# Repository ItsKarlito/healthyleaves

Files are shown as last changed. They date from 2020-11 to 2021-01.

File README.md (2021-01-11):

# ELEC/COEN 390 Engineering Team Design Project

**HealthyLeaves** is consumer electronics device used to monitor the vitals of any plant. Using a combination of powerful hardware and software, HealthyLeaves guarantees healthier and longer lasting house plants.

## Contributors
Daniel Savin (ELEC)  
Jun Young David Kim (ELEC)  
Karl Noory (ELEC)  
Thomas Tran (COEN)  
Vily Badea (COEN)  

## Supervision
Bipin Patel  
Dr. Wahab Hamou Lhadj  

## Technology Stack
Android Studio IDE  
Arduino C/C++  
Arduino IDE  
ESP32 Microcontroller  
Firebase  
Git  
Java  
KiCAD  
LDR Light Sensor  
SEN0193 Capcitive Moisture Sensor  
TensorFlow  
TMP36 Temperature Sensor  

## App Installation Guide
### Steps
1. Clone project repository.
1. Open PlantMonitor Android project in .software/PlantMonitor.
1. Build Gradle of PlantMonitor Android app.
1. Run PlantMonitor Android app.
1. Open PlantIdentier Android project in .software/PlantIdentifier.
1. Build Gradle of PlantIdentifier Android app.
1. Run PlantIdentifier Android app.
1. You can now access the application called "Healthy Leaves".

### Notes
Make sure the filepath for the SDK manager points to your own directory.  
The build.gradle file will need to specify the version of your own Android Studio version.  
A device is not requiered to run the app.  
To pair the device to our demo device on Karl's plant, enter the device code as "-MLuKU9iZdUl5zLGsuPz".  

## Microcontroller Setup Guide
### Steps
1. Clone project repository.
1. Download and install the [FirebaseESP32](https://www.arduino.cc/reference/en/libraries/firebase-esp32-client/) client library. Import the library into the [Arduino IDE](https://www.arduino.cc/en/software).
1. Open the HealthyLeaves Arduino project located at engineering-team-design-project/hardware/sparkfunESP32/HealthyLeaves/
1. Edit sketch with proper WiFi and Firebase credentials.
1. Attach the HealthyLeaves sensor shield to the SparkFun ESP32 Thing.
1. Connect the SparkFun ESP32 Thing microcontroller to your computer via USB port. Follow the steps [here](https://learn.sparkfun.com/tutorials/esp32-thing-hookup-guide) if the Arduino IDE does not recognise the SparkFun ESP32 Thing.
1. Compile and upload the sketch to the SparkFun ESP32 Thing.
1. Place the end of the moisture sensor located on the HealthyLeaves sensor shield into the plant you want to monitor.

### Notes
A device is not requiered to run the app.  
To pair the device to our demo device on Karl's plant, enter the device code as "-MLuKU9iZdUl5zLGsuPz" in the HealthyLeaves Arduino sketch.  

## Pictures and Screenshots
### Android Application
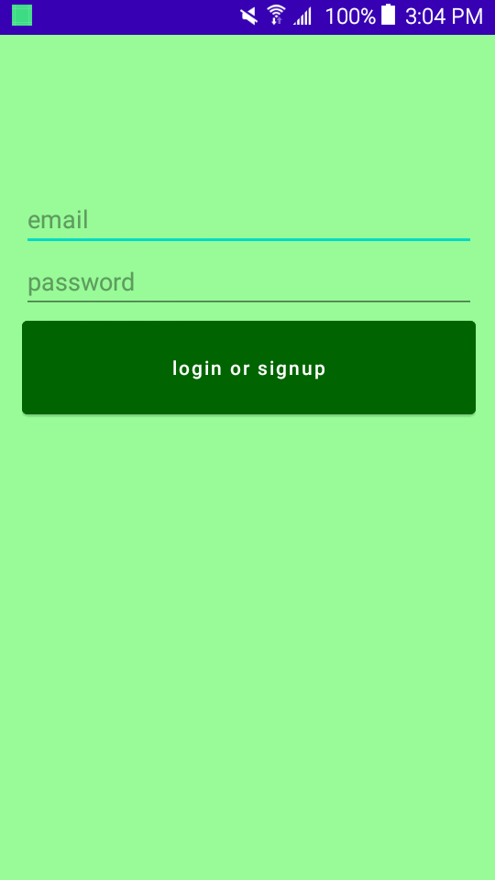
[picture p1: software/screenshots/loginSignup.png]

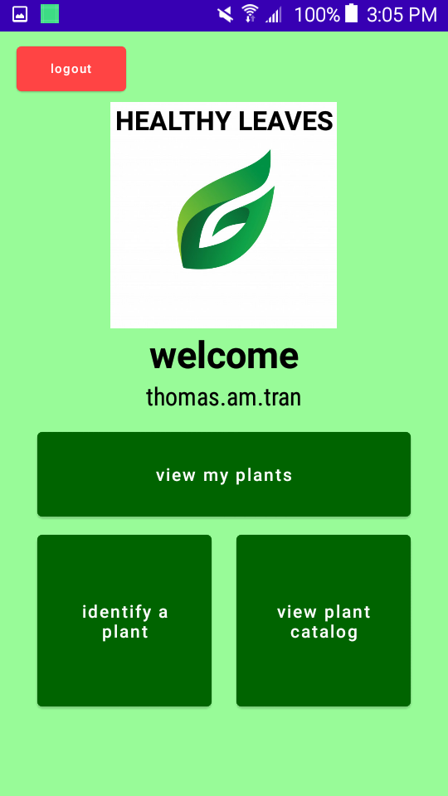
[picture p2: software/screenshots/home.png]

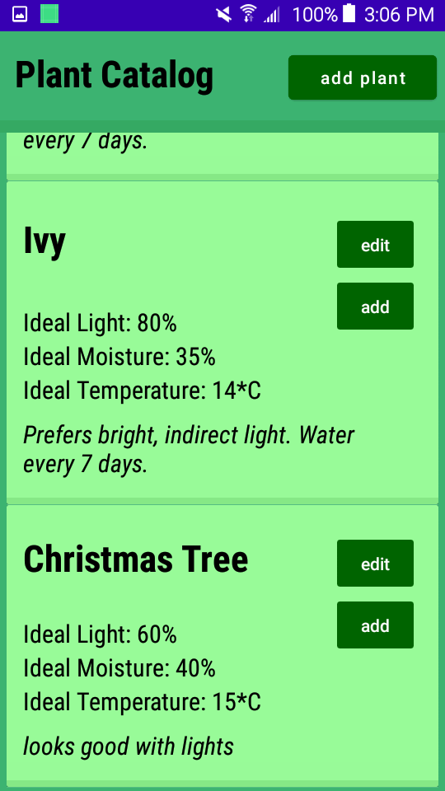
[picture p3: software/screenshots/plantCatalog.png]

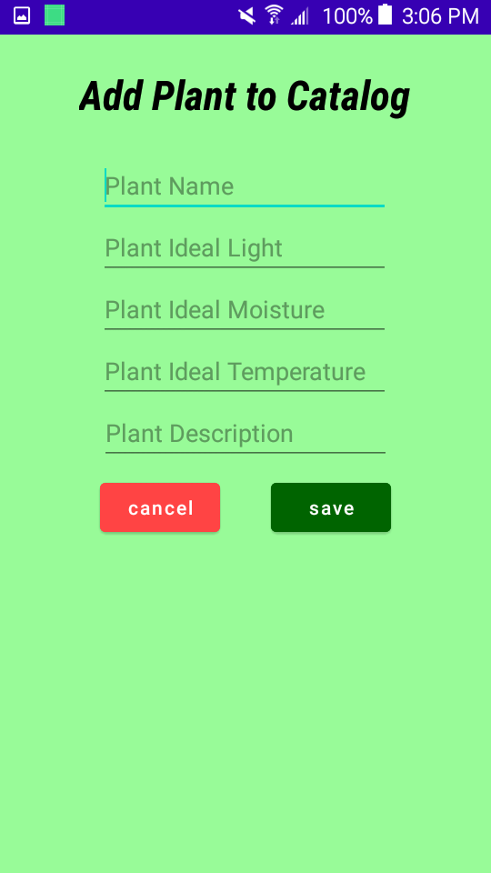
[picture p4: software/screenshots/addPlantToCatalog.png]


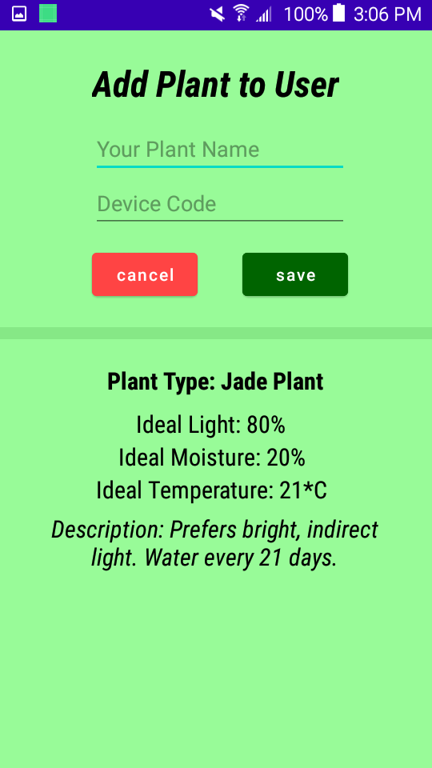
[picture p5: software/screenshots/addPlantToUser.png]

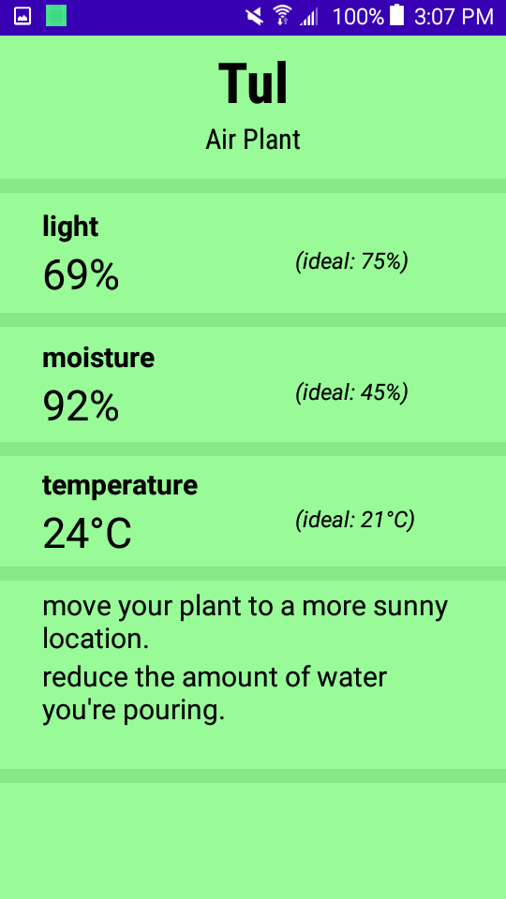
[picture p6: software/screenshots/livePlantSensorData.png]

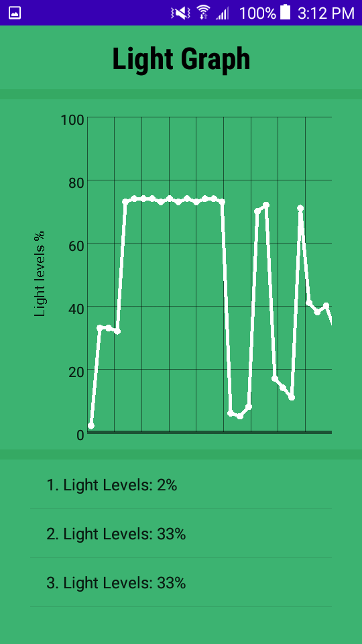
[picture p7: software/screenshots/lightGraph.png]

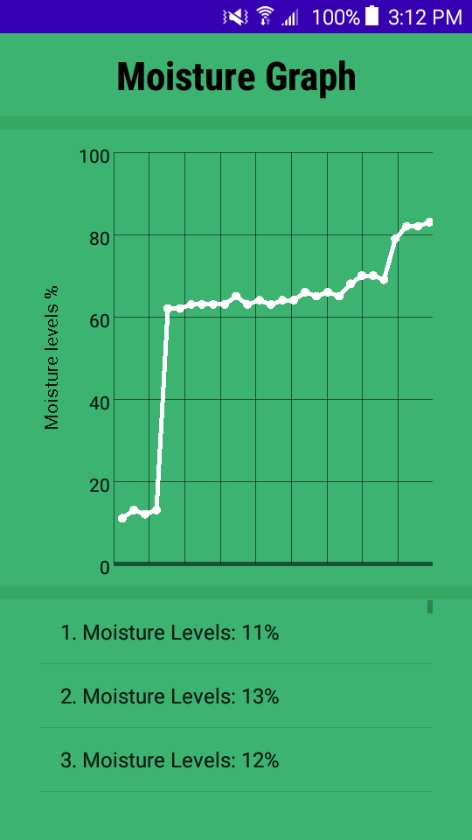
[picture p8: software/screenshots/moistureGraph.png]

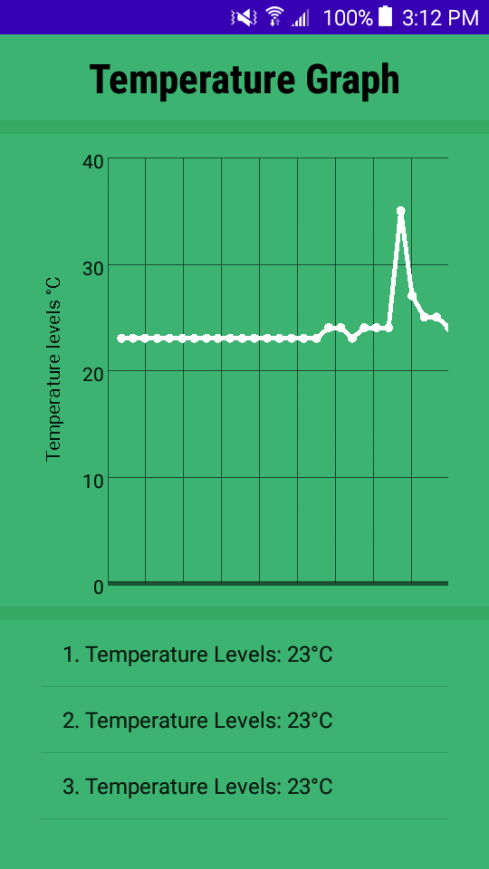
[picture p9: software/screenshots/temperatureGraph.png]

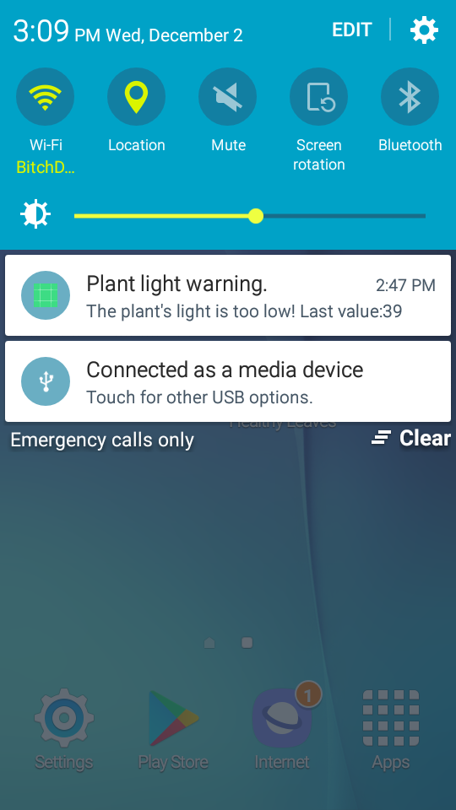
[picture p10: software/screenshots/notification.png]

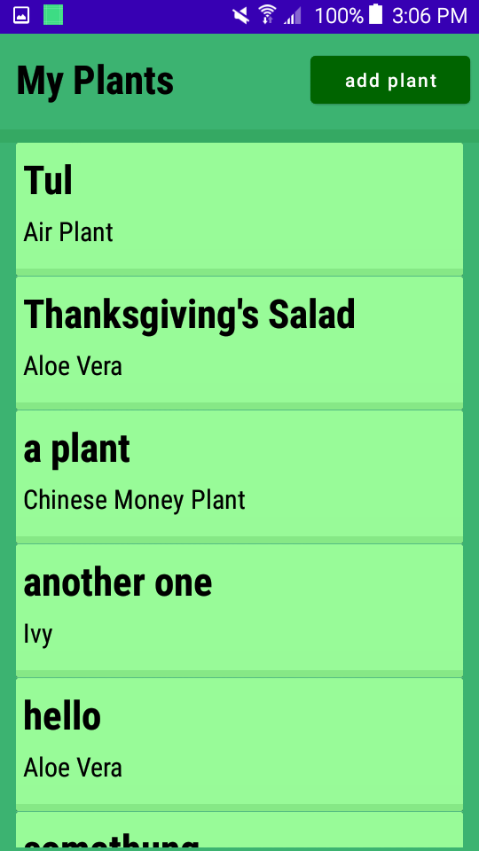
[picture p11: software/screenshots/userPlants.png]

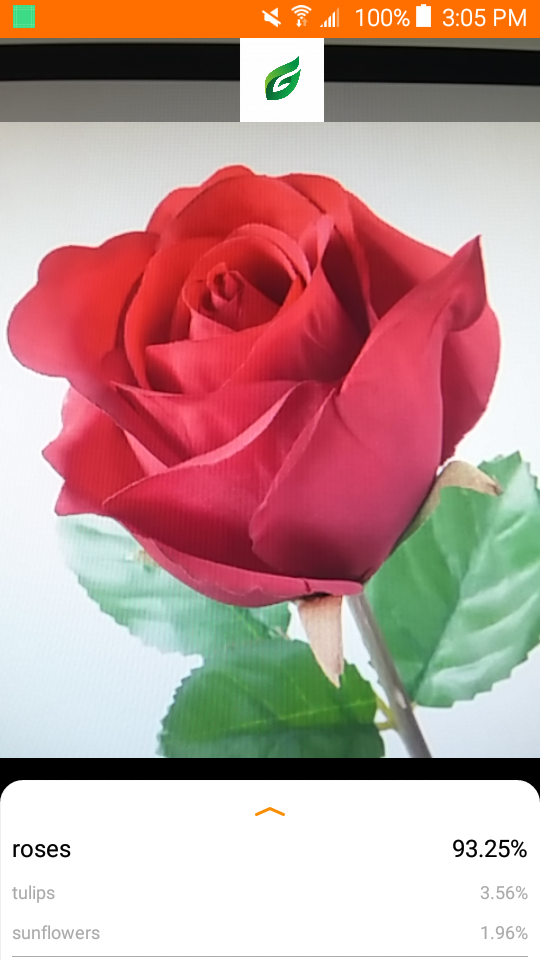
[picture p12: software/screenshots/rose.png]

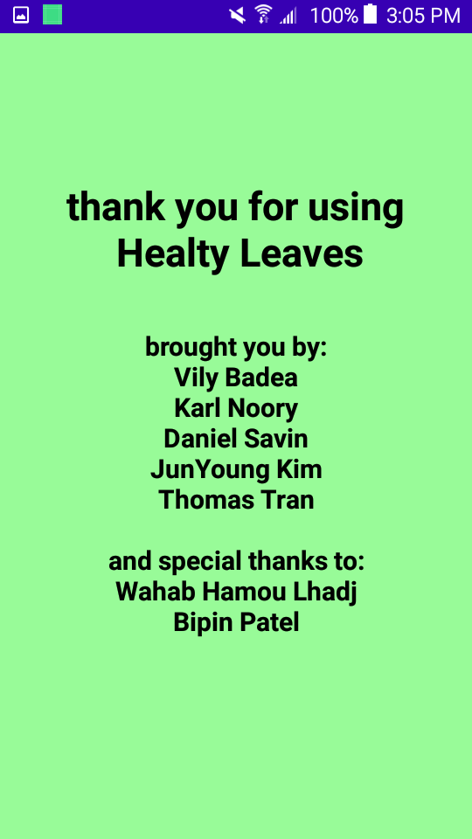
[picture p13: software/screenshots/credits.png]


### Hardware
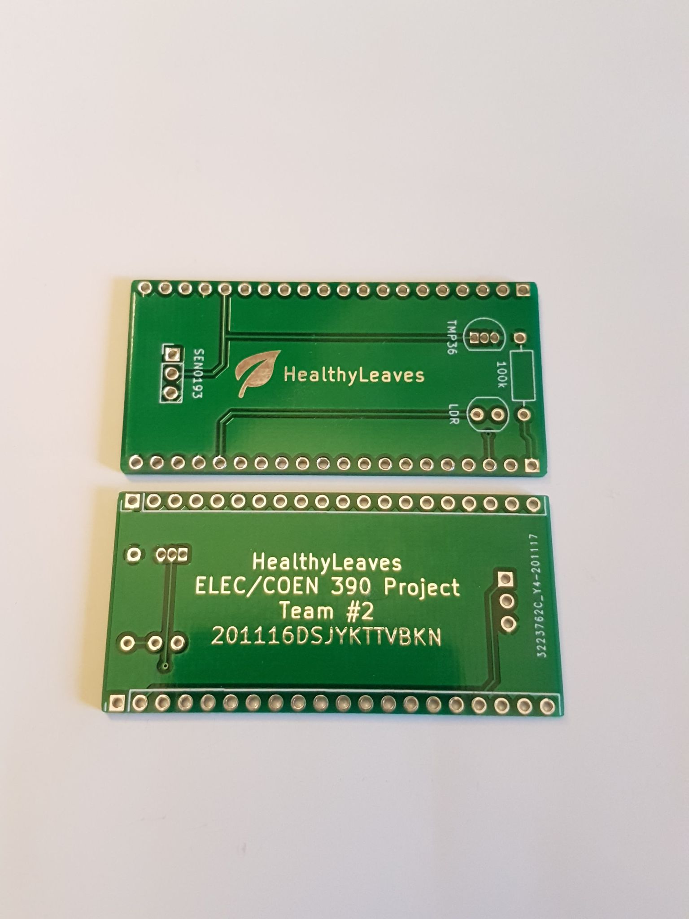
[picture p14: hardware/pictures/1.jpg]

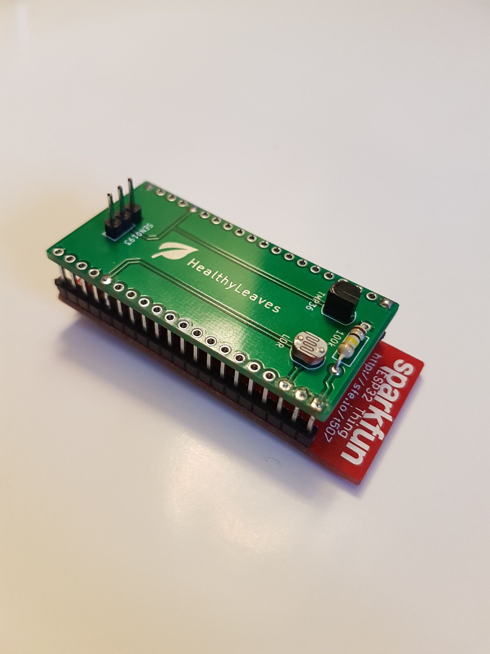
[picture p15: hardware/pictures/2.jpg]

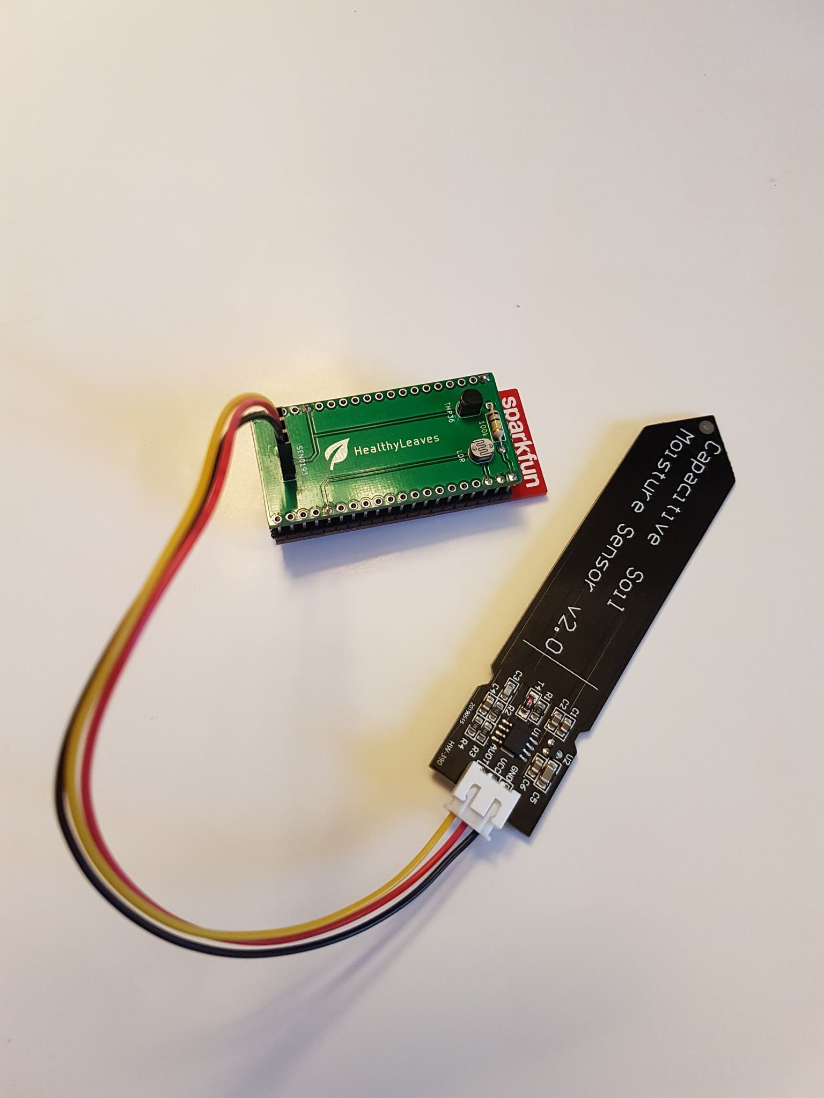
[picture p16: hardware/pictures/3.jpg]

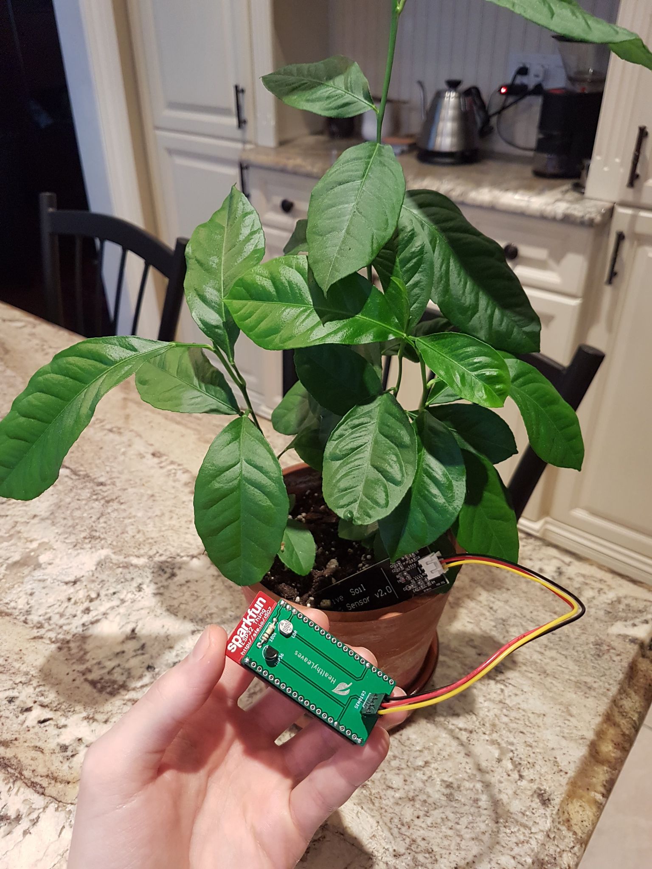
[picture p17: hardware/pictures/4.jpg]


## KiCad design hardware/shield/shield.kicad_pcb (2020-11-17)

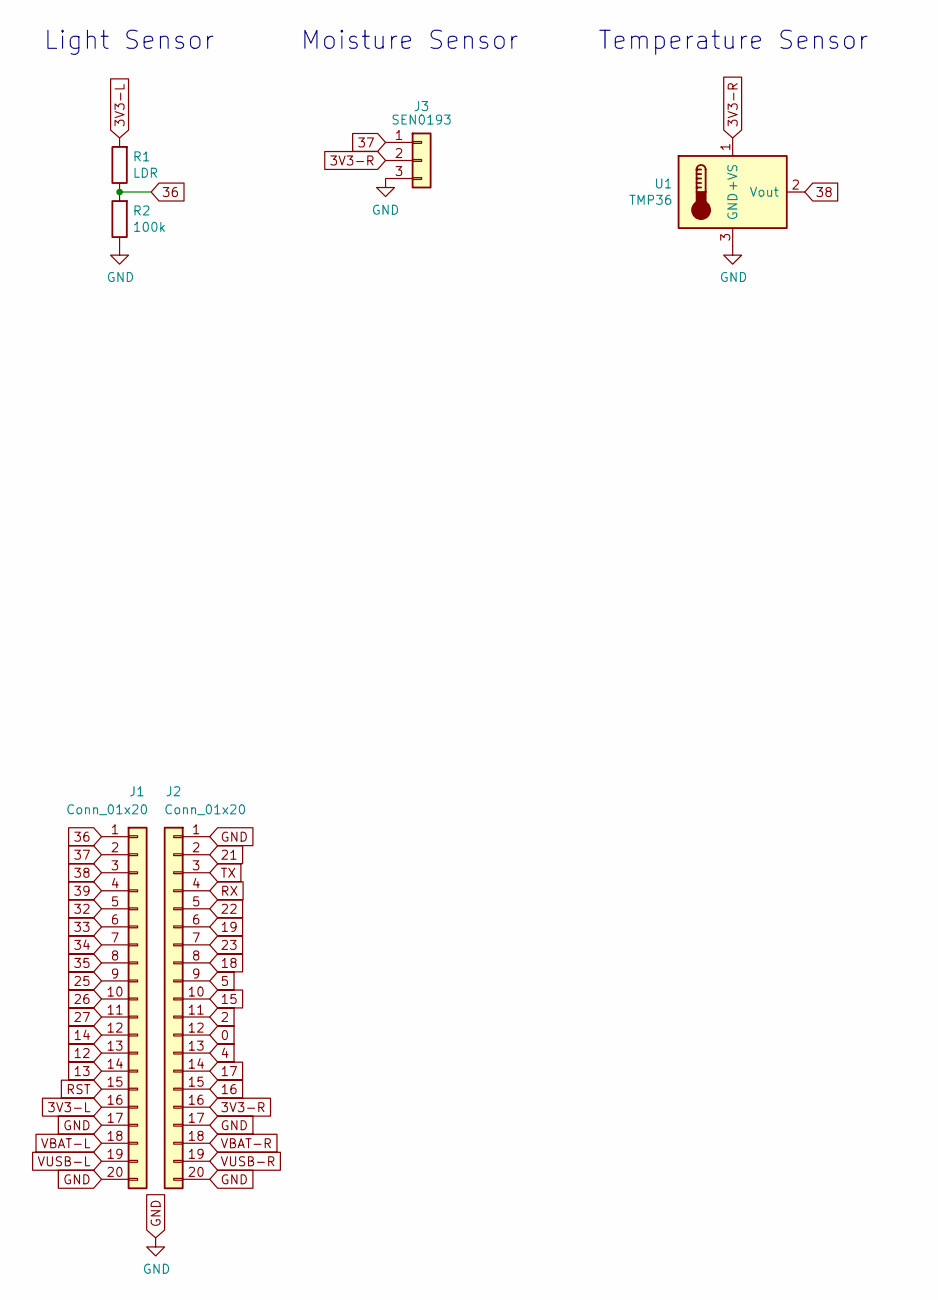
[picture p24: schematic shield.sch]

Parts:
J1, J2: Conn_01x20; PinHeader_1x20_P2.54mm_Vertical
J3: SEN0193; PinHeader_1x03_P2.54mm_Vertical
R1: LDR; R_LDR_4.9x4.2mm_P2.54mm_Vertical
R2: 100k; R_Axial_DIN0207_L6.3mm_D2.5mm_P10.16mm_Horizontal
U1: TMP36; TO-92L_Inline

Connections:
0: J2.12
2: J2.11
3V3-L: J1.16, R1.2
3V3-R: J2.16, J3.2, U1.1 (+VS)
4: J2.13
5: J2.9
12: J1.13
13: J1.14
14: J1.12
15: J2.10
16: J2.15
17: J2.14
18: J2.8
19: J2.6
21: J2.2
22: J2.5
23: J2.7
25: J1.9
26: J1.10
27: J1.11
32: J1.5
33: J1.6
34: J1.7
35: J1.8
36: J1.1, R1.1, R2.2
37: J1.2, J3.1
38: J1.3, U1.2 (Vout)
39: J1.4
GND: J1.17, J1.20, J2.1, J2.17, J2.20, J3.3, R2.1, U1.3 (GND)
RST: J1.15
RX: J2.4
TX: J2.3
VBAT-L: J1.18
VBAT-R: J2.18
VUSB-L: J1.19
VUSB-R: J2.19

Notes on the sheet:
Light Sensor
Temperature Sensor
Moisture Sensor

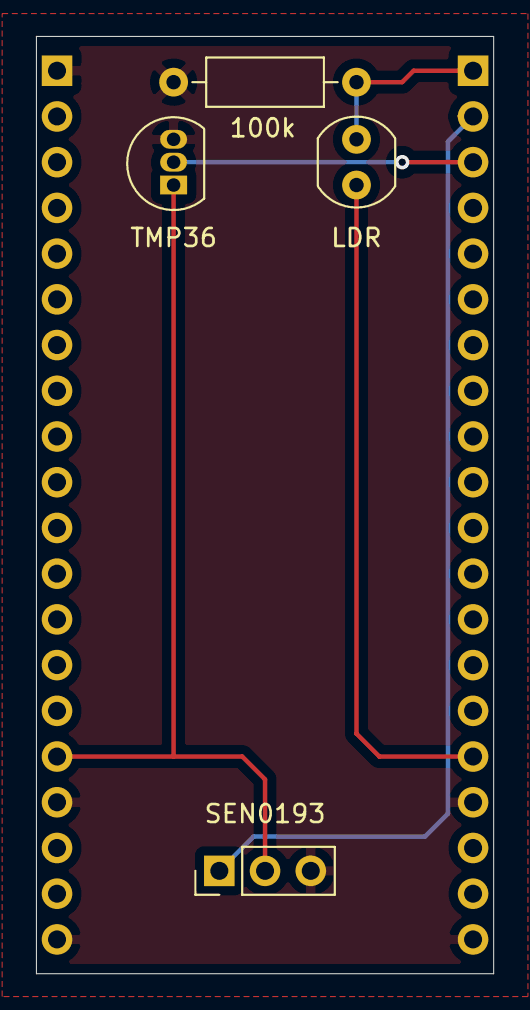
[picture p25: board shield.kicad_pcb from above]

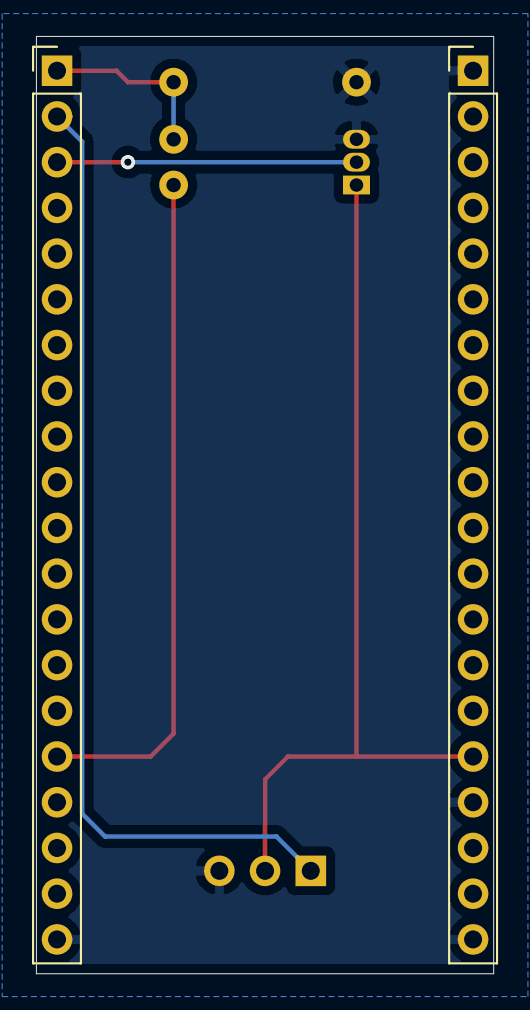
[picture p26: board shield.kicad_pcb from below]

Board: 2 copper layers, 25.4 x 52.1 mm, 6 parts (2 on the bottom side), 6 nets.

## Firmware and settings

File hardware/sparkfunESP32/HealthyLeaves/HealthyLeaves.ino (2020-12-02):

/*
HealthyLeaves - ELEC/COEN 390 Team Project
Last modified: 2020-11-14
Hardware code for the HealthyLeaves device.
*/

//libraries
#include <WiFi.h>
#include <time.h>
#include <FirebaseESP32.h>

//definitions
#define SYNC 5000

//Firebase authentication
#define FIREBASE_HOST "https://healthyleaves-a5549.firebaseio.com/"
#define FIREBASE_AUTH "BlLToB9zFk5KjOzP3HkGUeBjVcWOsTKe56QPySID"
FirebaseData firebaseData;//define FirebaseESP32 data object

//WiFi authentication
#define WIFI_SSID "BELL197"
#define WIFI_PASSWORD "6527757A"

//time configuration
const char* ntpServer = "pool.ntp.org";//time server
const long  gmtOffset_sec = 0;//correction for timezone
const int   daylightOffset_sec = 0;//daylight offset

//sensors available
enum Sensor {light, moisture, temperature};//list of sensors

//user data identification
int id = 0;
String userPlantId = "-MLuKU9iZdUl5zLGsuPz";

void setup()
{
  //initialize Serial Monitor
  Serial.begin(115200);

  //initialize WiFi
  WiFi.begin(WIFI_SSID, WIFI_PASSWORD);
  Serial.print("Connecting to Wi-Fi");
  while (WiFi.status() != WL_CONNECTED)
  {
    Serial.print(".");
    delay(2000);
  }
  Serial.println();
  Serial.print("Connected with IP: ");
  Serial.print(WiFi.localIP());
  Serial.println();

  //initialize Firebase
  Firebase.begin(FIREBASE_HOST, FIREBASE_AUTH);
  Firebase.reconnectWiFi(true);
  Firebase.setReadTimeout(firebaseData, 1000 * 60);
  Firebase.setwriteSizeLimit(firebaseData, "tiny");

  // Configure System Time
  configTime(gmtOffset_sec, daylightOffset_sec, ntpServer);
}

void loop()
{
  writeToDatabase(light, getLight());
  delay(SYNC);
  writeToDatabase(moisture, getMoisture());
  delay(SYNC);
  writeToDatabase(temperature, getTemperature());

  Serial.println("********************");
  Serial.println();
  id++;//create a new reading
  delay(SYNC);
}

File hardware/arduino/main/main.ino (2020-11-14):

/****************************************************/
//Name: Sensor Read
//Author: dansavin11@gmail.com
//Last modified: 2020-11-10
//Description: Program reads moisture data from a
//             capacitive sensor and translates it
//             to sensible readings.
/****************************************************/

//variables declaration
int moistureData = 0;//A0

void setup()
{
  Serial.begin(9600);//start serial comm with pc
}

void loop()
{
  moistureData = getMoisture();
  Serial.println(moistureData);
  delay(100);
}

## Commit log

2020-10-30 link established between esp32 and firebase
2020-11-06 initialized kicad project, sparkfunESP32 shield
    [shield.kicad_pcb, shield.sch]
2020-11-06 added sparkfunESP32 schematic
2020-11-06 added ESP32 datasheet
2020-11-06 sparkfunESP32 shield pcb, temperature and light sensors
    [shield-B_Cu.gbr, shield-B_Mask.gbr, shield-Edge_Cuts.gbr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]
2020-11-09 refactored the code, added the edit plant catalog feature including the activity, the button that goes to that activity with the adequate intent and the functionalities to the firebase database, fixe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
2020-11-09 fixed a bug with the add plant button in plant catalog and started implementation of OwnsA relationship creation
2020-11-10 added logout button and fixed .gitignore file
2020-11-10 Revert "added logout button and fixed .gitignore file"
2020-11-11 logout button
2020-11-11 OwnsA relationship can be created properly from the catalog page using the add button. User plants can be created by saving the plantID and userID and a name as a tuple
2020-11-11 added Arduino code for moisture sensor read (no Firebase)
2020-11-12 fixed userPlantsList display bug and feature is completed. A prop page of the plant profile has been implemented too
2020-11-16 updated shield for sparkfunESP32
    [shield-B_Cu.gbr, shield-B_Mask.gbr, shield-B_Paste.gbr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]
2020-11-17 updated pcb connector, added logo and version number
    [shield-B_Cu.gbr, shield-B_Mask.gbr, shield-B_Paste.gbr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]
2020-12-01 fixed multiple bugs, improved UI, actions recommendations feature, arduino pairing both ways possible
2020-12-02 light graph changes copied to moisture and temperature graph
